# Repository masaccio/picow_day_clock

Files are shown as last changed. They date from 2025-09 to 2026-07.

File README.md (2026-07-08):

# Raspberry Pi Pico Day of Week Clock

## Current status

This project **is a work in progress**.

The clock is now feature complete from a software perspective though if this were scaled up for sale, it would need user-level configuration using a Wi-Fi connection and a web-server to provide the credentials and would also need some means of initiating a factory reset. Better still would be bluetooth discovery from a phone app to configure the clock for things like timezones, colors and fonts as well as the Wi-Fi credentials. The clock build looks like this:

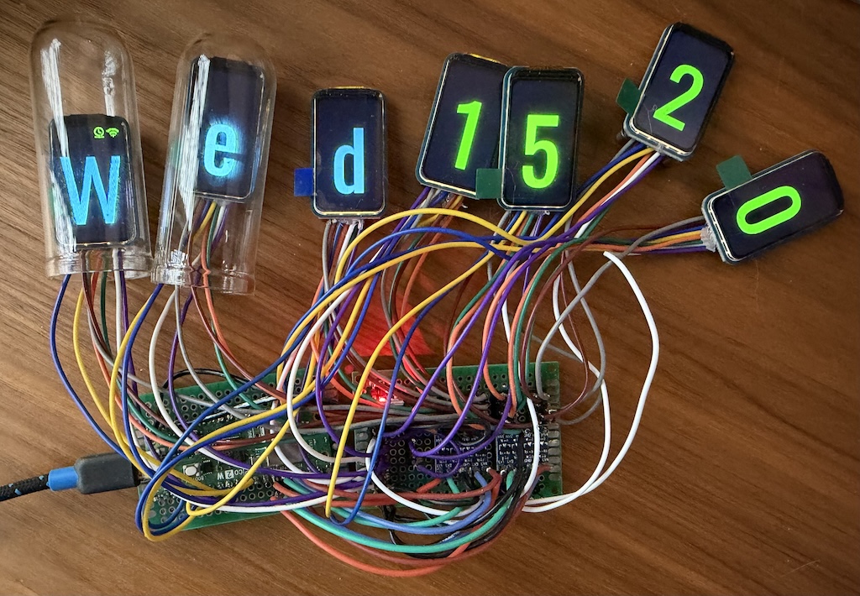
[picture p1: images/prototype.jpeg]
Current prototype


Next steps in the project are:

* Move away from the Waveshare LCD as they are quite bulky despite my surgery and I now plan to build my own backlight circuitry and drive a bare LCD
* Add a factory reset button to the design (software is complete)
* Add an alarm LED to the design for terminal failure of the LCDs or any other unrecoverable fault
* Design a 2-layer PCB to host the design as the current soldered design is too fragile
* Build a walnut enclosure

## Introduction

This project is the software, hardware design and clock enclosure design for an LCD clock driven by the Raspberry Pi Pico 2 W. The clock design is inspired by the idea of a [Nixie](https://en.wikipedia.org/wiki/Nixie_tube) clock but uses LCDs so that the display is brighter and clearly visible in daylight. The clock is intended to be wall-mounted so the read is left a little messy to simplify the electronics build.

The project is *not* compatible with earlier versions of the Pico and requires the CYW43439 Wi-Fi chip present in the Pico 2 W to function correctly.

## Software Operation

The pin-out and Wi-Fi settings are hard-coded into the project at build time. After the Pico firmware boots, the software will:

* Initialize all 7 LCD modules writing to the UART and exiting if this fails
* Create a Wi-Fi connection to the hard-coded Wi-Fi network
* Get the current time from public NTP servers
* Display the abbreviated day of week on the first three LCDs and the current time in hours in minutes on the remaining 4 displays

NTP syncs start at once per day and respect back-off requests from the server if this is too frequent. The timer itself runs once per second and any NTP drift that occurs daily is compensated for in these timer callbacks.

### Diagnostics

A watchdog timer runs on the clock and reboots the Pico if there is no activity for `WATCHDOG_TIMEOUT_MS` which is 3 seconds by default. On reboot, the clock reconnects to Wi-Fi and resyncs with NTP.

The clock displays icons along the top edge of LCD1 when errors occur. The icons indicate watchdog status, NTP status and Wi-Fi status. They are coloured red for errors and green for normal status and indicate the nature of the error that occurred such as a Wi-Fi authentication problem or network timeout.

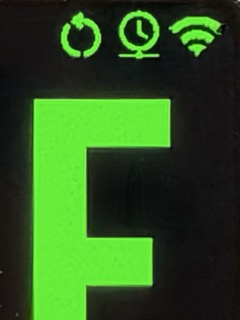
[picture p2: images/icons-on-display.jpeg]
Example display icons


If the LCD cannot be initialized, the clock prints diagnostics to `stdout` as a last resort.

### Timezones and Daylight Saving Time

The software takes into consideration daylight saving time (DST) and timezones as configured in flash. Timezones are configured as hour/half-hour offsets matching those known across the globe. The following DST rules are available which covers all regions:

| Region / Pattern | DST Start Rule (Clocks go forward) | DST End Rule (Clocks go back) | Shift |
| --- | --- | --- | --- |
| **None** (Japan, India, Arizona, Hawaii) | *Does not observe DST* | *Does not observe DST* | 0 |
| **North America** (US, Canada) | 2nd Sunday in March at 02:00 | 1st Sunday in November at 02:00 | +1 Hour |
| **Europe / UK** (EU, UK, Switzerland) | Last Sunday in March at 01:00 UTC | Last Sunday in October at 01:00 UTC | +1 Hour |
| **Australia** (Most states) | 1st Sunday in October at 02:00 | 1st Sunday in April at 03:00 | +1 Hour |
| **New Zealand** | Last Sunday in September at 02:00 | 1st Sunday in April at 03:00 | +1 Hour |
| **Chile** | 1st Saturday in September at 24:00 | 1st Saturday in April at 24:00 | +1 Hour |
| **Israel** | Friday before the last Sunday in March | Last Sunday in October at 02:00 | +1 Hour |

## Configuration

Configuration is stored in Flash and the clock will reconfigure itself when:

* an invalid configuration is detected in flash
* the factory reset button is held for 3 seconds during boot
* the factory reset button is held for 3 seconds normal operation

If factory reset is hed during boot, the clock will erase the stored flash configuration regardless of whether it is valid or not making holding the reset during normal operation harmless until the configuration is saved.

During configuration, the clock starts a Wi-Fi access point with the prefix `Pico-Day-Clock-Setup` and the last part of the Pico's MAC address. Connecting a device to this Wi-Fi network should start a captive portal, but if not, the clock's default IP address is `192.168.4.1` and you can direct your browser to `http://192.168.4.1/`. The following form configures the clock:

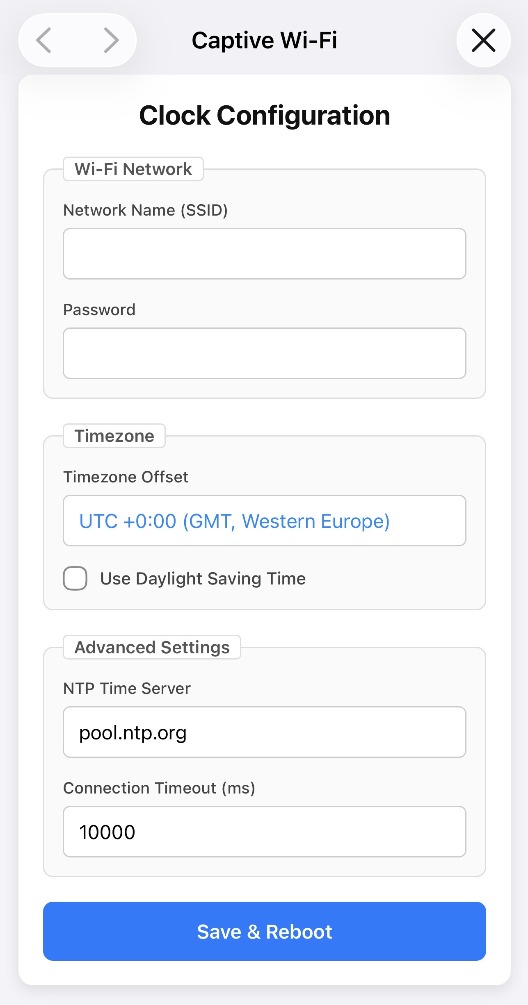
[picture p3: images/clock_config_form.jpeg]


The minimum setup is a valid Wi-Fi SSID and password. If the password is incorrect, you must force a factory reset as the clock will try indefinitely to connect to the configured Wi-Fi.

## Build and Testing

The software is expected to build on Mac, Linux and Windows hosts and should be able to be imported into the Raspberry Pi Pico extension to Visual Studio Code. The Pico target build uses the standard Pico SDK tooling, but the native tests and coverage require LLVM for Clang and the coverage tools.

Tests for the core clock functionality and error handling is largely complete through some very basic mocking of the Pico SDK. The [code](tests/mock.c) for the mocking is by no means complete and is just the very minimum required to make the clock function and generate errors that might occur such as DNS timeouts.

The tests run on the host and assume Clang is available. **Windows hosts are unsupported for testing** as the host implementation of `time_t` is incompatible with the NTP implementation which assumes uses timestamps starting in 1900 and in turn this requires 64-bit `time_t`.

Automated CI is provided by [GitHub runners](.github/workflows/build.yml).

## Debug

On boot, all LCDs are initialized first and diagnostic messages are displayed on the LCD1 as Wi-Fi and then NTP is initialized. On success, the clock starts. If any error is unrecoverable, signaled by a status message in red, the clock will not start and the diagnostics will remain. If the diagnostics do not appear at all, there is a problem with the LCD connections or the LCD driver. The following CMake configuration is available for debug to the UART:

* `CLOCK_DEBUG_ENABLED`: debug messages from the day of week clock itself
* `PICO_CYW43_ARCH_DEBUG_ENABLED`: SDK built-in debug of Wi-FI connections
* `LWIP_MALLOC_DEBUG`: SDK built-in memory allocation debug
* `LWIP_PROTOCOL_DEBUG`: SDK built-in UDP debug

## Pico pinout

The pinout for the LCD is defined in `config.h` using a series of C macros `LCD1_GPIO_xxx`. The backlight is shared across all of the LCDs as there is no need to control the dimming of the LCDs individually.

| Pin to device mapping | Name | Pin | Pico  | Pin | Name | Pin to device mapping |
|---|---|-----| ----- |-----|---|---|
| Debug Probe RX | GP0 | 1 | XXXXX | 40  | VBUS 5V | |
| Debug Probe TX | GP1 | 2 | XXXXX | 39  | VSYS 5V | DollaTek VIN |
| Debug Probe GND | GND | 3 | XXXXX | 38  | GND | LCD GND |
| LCD 1 chip select (CS) | GP2 | 4 | XXXXX | 37  | 3V3 En | |
| LCD 2 chip select (CS) | GP3 | 5 | XXXXX | 36  | 3V3 Out | |
| LCD 3 chip select (CS) | GP4 | 6 | XXXXX | 35  | ADC VRef  | |
| LCD 4 chip select (CS) | GP5 | 7 | XXXXX | 34  | GP28 A2 | |
| | GND | 8 | XXXXX | 33  | ADC Gnd | |
| LCD 5 chip select (CS) | GP6 | 9 | XXXXX | 32  | GP27 A1 | |
| LCD 6 chip select (CS) | GP7 | 10  | XXXXX | 31  | GP26 A0 | |
| LCD 7 chip select (CS) | GP8 | 11  | XXXXX | 30  | RUN | |
| Factory reset | GP9 | 12  | XXXXX | 29  | GP22 | |
| | GND | 13  | XXXXX | 28  | GND | |
| Shared clock (CLK) | GP10 | 14  | XXXXX | 27  | GP21 | |
| Shared MOSI (DIN) | GP11 | 15  | XXXXX | 26  | GP20 | |
| Shared reset (RST) | GP12 | 16  | XXXXX | 25  | GP19 | |
| Shared backlight (BL) | GP13 | 17  | XXXXX | 24  | GP18 | |
| | GND | 18  | XXXXX | 23  | GND | |
| Shared data/command (DC) | GP14 | 19  | XXXXX | 22  | GP17 | |
| Diagnostic LED | GP15 | 20  | XXXXX | 21  | GP16 | |

## Electrical Design

The LCD module expects a 3.3V supply and the [datasheet for the Waveshare 1.47inch LCD](https://files.waveshare.com/upload/9/99/1.47inch_LCD_Datasheet.pdf) indicates that the backlight draws 60-90mA. All the LCDs can therefore be driven by a single voltage regulator such as the DollaTek 1117:

* VIN: 5V VSYS from the USB power supply shared with the Pico
* VOUT: LCD VCC, shared across all LCD modules
* GND: any GND pin on the Pico

The BL backlight pin of the LCD module is not the actual  LCD backlight; it is a control pin to the LCD module's TXB0108PWR level shifter so can also be shared across all LCDs and, like the other control signals, driven directly from the Pico.

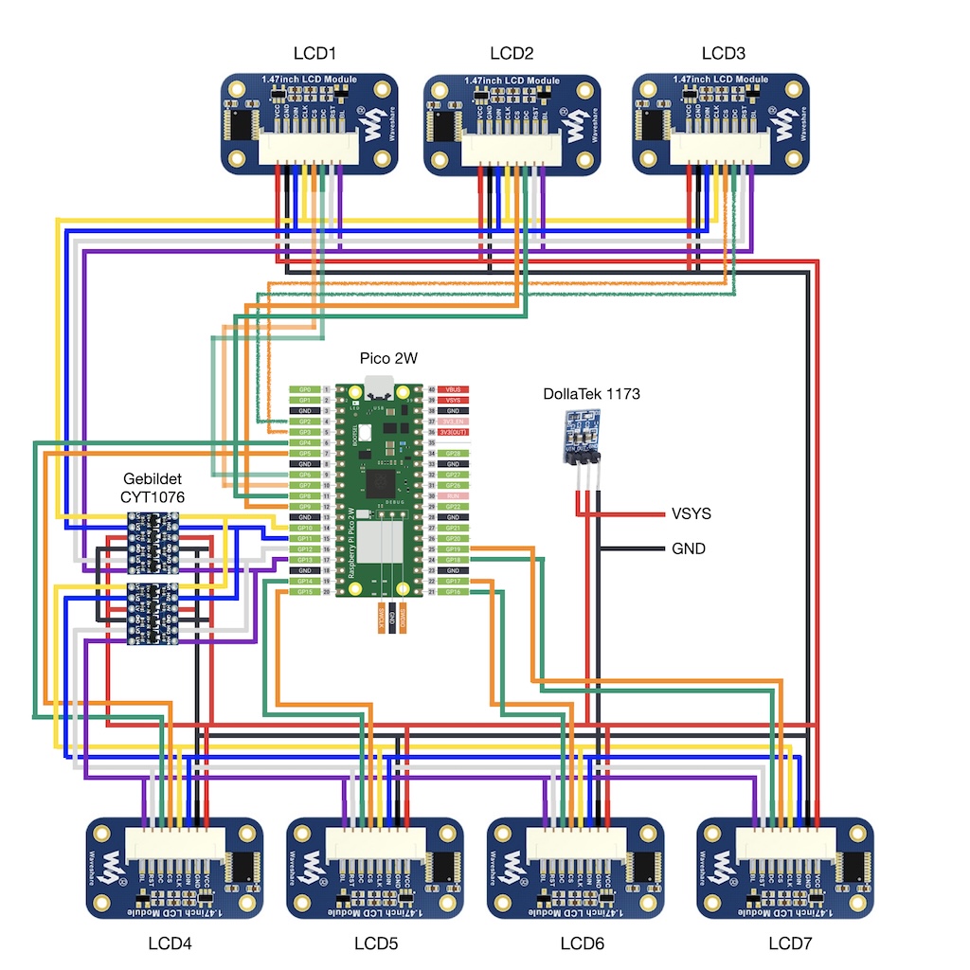
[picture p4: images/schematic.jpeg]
Clock schematic diagram


The Pico has insufficient drive strength to drive the control signals of 7 LCDs simultaneously, so a logic level converter with the VA and VB tied to 3V3 is used to increase the drive strength and buffer between the Pico and the LCDs. Care must be taken to choose a level shift with sufficient drive strength; a single TXB0108 proved insufficient and the final design uses two four-channel Gebildet CYT1076 level shifters. One CYT1076 drives the day of week LCDs (LCD1-3) and the other the time LCDs (LCD4-7).

## Mechanical design

I chose the Waveshare LCD because it comes with a socket that has a wired plug with 2.54mm pin connectors for easy prototyping. For the final clock, this connector gets in the way of the wires hiding neatly behind the LCD. There are 172x320 LCD displays that are based on the ST7789 that come with an FPC connector which is neatly connected on the narrow edge of the display. The bare LCD with the FPC connector has the disadvantage for the hobbyist that you need to add a ZIF socket and then break that out into something with a wider pitch to solder. The connector on the Waveshare board can be desoldered using solder braid and the connector carefully snipped off using flush snippers. The Waveshare module also has 2mm brass mounting holes which makes mounting the LCDs securely simpler. The main drawback of the approach is that the read of the LCD is quite messy, but the intended use is for a wall-mounted clock. The soldered connections look like this (please forgive the terrible soldering skills; I am out of practice):

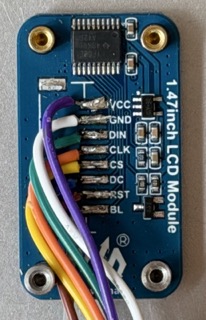
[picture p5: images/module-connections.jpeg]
Soldered connections to LCD module


The glass domes appear to be referred to as "glass dome cloche covers with cork bases" and are available from Chinese manufactures on sites like [TEMU](https://www.temu.com/). Since the class is reasonably heavy 2mm thick glass, the 25mm domes are too narrow in the internal diameter for the LCD so 28mm domes are required. Unfortunately 71mm long so they need to sit about 25mm below the top of the clock so that the LCDs are comfortable in the upper section of the dome. The domes sit inside a 4mm brass frame to which the LCDs can be held using M2 machine screws:

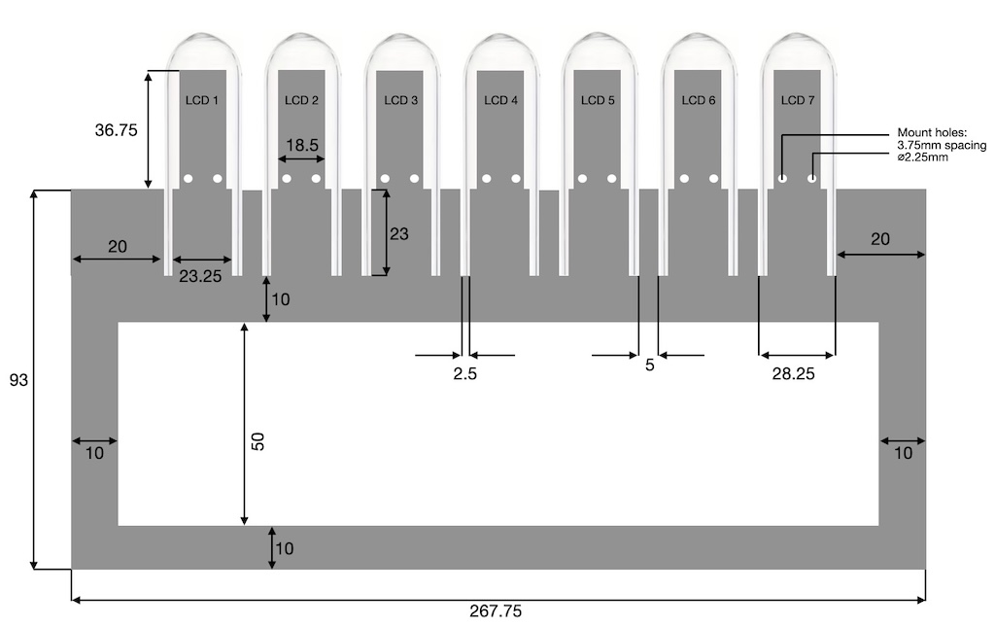
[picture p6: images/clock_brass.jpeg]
Brass plate design


The brass frame is laser cut from 4mm brass using a CAD file that is generated using `scripts/generate-dxf.py`. Assuming CMake has generated the Python virtual environment in the `build` folder, you can build the DXF file (`generated/clock_brass.dxf`) using:

``` bash
source build/scripts_venv/bin/activate
pip install ezdxf
python3 scripts/create-cad-drawing.py
```

It's also possible to generate a 3D model using Python for use as a 3D printing prototype to check that that everything aligns correctly:

``` bash
source build/scripts_venv/bin/activate
pip install cadquery cadquery-ocp
python3 scripts/create-3d-model.py
```

The brass frame is then sandwiched between two rectangular woden boxes with no lids. The USB power cable is fed through one box and plugs into the Pico's USB port which simplifies the electrical design.

## Credits

ST7789 init and driver code is derived from the [Waveshare Sample Demo](https://www.waveshare.com/wiki/1.47inch_LCD_Module) for the Waveshare 1.47inch LCD. The driver is [licensed](licenses/waveshare.txt) by the Waveshare team under an MIT license.

NTP driver code is derived from [pico_ntp_client](https://github.com/raspberrypi/pico-examples/tree/master/pico_w/wifi/ntp_client) in the [Raspberry Pi Pico SDK Examples](https://github.com/raspberrypi/pico-examples) which is [licensed](raspberry-pi.txt) under a BSD license.

The access point and associated DHCP/DNS server are derived from [pico_access_point](https://github.com/raspberrypi/pico-examples/tree/master/pico_w/wifi/access_point) in the [Raspberry Pi Pico SDK Examples](https://github.com/raspberrypi/pico-examples) which is [licensed](raspberry-pi.txt) under a BSD license.

Variable width fonts replace the fixed-width fonts in the Waveshare examples, but the C data structures are ultimately derived from work by STMicroelectronics [licensed](licenses/stm.txt) under the 3-clause BSD license.

The digit fonts included in the repository are [Bebas Neue Regular](https://fonts.google.com/specimen/Bebas+Neue) which is [licensed](licenses/BebasNeue-OFL.txt) under the Open Font License, and [Oswald](https://fonts.google.com/specimen/Oswald) which is also [licensed](licenses/Oswald-OFL.txt) under the Open Font License.

The text font used in display diagnostics during boot is [Roboto Medium](https://fonts.google.com/specimen/Roboto) which is [licensed](licenses/Roboto-OFL.txt) under the Open Font License.

Icons in this project are derived from [Google Material Design Icons](https://github.com/google/material-design-icons), which are licensed under the [Apache License 2.0](https://github.com/google/material-design-icons/blob/master/LICENSE). The icons have been resized and converted to C bitmaps for use in this project, and new icons have been derived to addition status badges.

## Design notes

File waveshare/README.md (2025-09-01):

# Waveshare 1.47inch LCD Module

The files here are copied from the [Waveshare Wiki](https://www.waveshare.com/wiki/1.47inch_LCD_Module) for the 1.47 inch LCD Module which is based off the ST7789V3 chipset.

The driver has been modified as follows:

* I2C and Infrared has been removed since the LCD used in this project only uses SPI.
* The pin configuration in `Dev_Config.h` has been replaced by config passed to `DEV_Module_Init()` to enable multiple displays from the single driver.

## Pico pinout

| Pin to device mapping | Name | Pin | Pico  | Pin | Name | Pin to device mapping  |
|---|---|-----| ----- |-----|---|---|
| Debug Probe RX | GP0 | 1 | XXXXX | 40  | VBUS 5V | |
| Debug Probe TX | GP1 | 2 | XXXXX | 39  | VSYS 5V | |
| Debug Probe GND | GND | 3 | XXXXX | 38  | GND | LCD GND |
| | GP2 | 4 | XXXXX | 37  | 3V3 En | |
| | GP3 | 5 | XXXXX | 36  | 3V3 Out | LCD VCC |
| | GP4 | 6 | XXXXX | 35  | ADC VRef  | |
| | GP5 | 7 | XXXXX | 34  | GP28 A2 | |
| | GND | 8 | XXXXX | 33  | ADC Gnd | |
| LCD 1 data/command (DC) | GP6 | 9 | XXXXX | 32  | GP27 A1 | |
| LCD 1 chip select (CS)  | GP7 | 10  | XXXXX | 31  | GP26 A0 | |
| LCD 2 data/command (DC) | GP8 | 11  | XXXXX | 30  | RUN | |
| LCD 2 chip select (CS)  | GP9 | 12  | XXXXX | 29  | GP22 | |
| | GND | 13  | XXXXX | 28  | GND | |
| Shared clock (CLK) | GP10 | 14  | XXXXX | 27  | GP21 | |
| Shared MOSI (DIN) | GP11 | 15  | XXXXX | 26  | GP20 | |
| Shared reset (RST) | GP12 | 16  | XXXXX | 25  | GP19 | |
| Shared backlight (BL) | GP13 | 17  | XXXXX | 24  | GP18 | |
| | GND | 18  | XXXXX | 23  | GND | |
| | GP14 | 19  | XXXXX | 22  | GP17 | |
| | GP15 | 20  | XXXXX | 21  | GP16 | |

## LCD connections

The default GPIO configuration is assumed, as defined in `lib/Config/DEV_Config.h`:

| Pico | LCD 1 | LCD 2 |
|---|---|---|
| 3V3 Out | VCC | VCC |
| GND | GND | GND |
| GP11 | DIN | DIN |
| GP10 | CLK | CLK |
| GP7 | CS | |
| GP6 | DC | |
| GP9 | | CS |
| GP8 | | DC |
| GP12 | RST | RST |
| GP13 | BL | BL |

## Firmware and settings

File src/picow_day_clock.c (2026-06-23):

#ifndef WIFI_SSID
#error "WIFI_SSID is not defined. Please define it in config.cmake or via a compile flag."
#endif

#ifndef WIFI_PASSWORD
#error "WIFI_PASSWORD is not defined. Please define it in config.cmake or via a compile flag."
#endif

#include <stdio.h>
#include <string.h>
#include <sys/time.h>
#include <time.h>

// Pico SDK
#ifndef TEST_MODE
#include "hardware/flash.h"
#include "hardware/gpio.h"
#include "hardware/sync.h"
#include "hardware/watchdog.h"
#include "pico/stdlib.h"
#include "pico/time.h"
#include "pico/util/datetime.h"
#else
#include "mock.h"
#include "test.h"

extern int test_main(void);
#endif

// Local includes
#include "bitmap.h"
#include "clock.h"
#include "config.h"

typedef struct
{
    uint16_t DC;
    uint16_t CS;
} lcd_pin_config_t;

static lcd_pin_config_t lcd_pin_config[NUM_LCDS] = {
    /* LCD 1 */ {.DC = LCD1_GPIO_DC, .CS = LCD1_GPIO_CS},
    /* LCD 2 */ {.DC = LCD2_GPIO_DC, .CS = LCD2_GPIO_CS},
    /* LCD 3 */ {.DC = LCD3_GPIO_DC, .CS = LCD3_GPIO_CS},
    /* LCD 4 */ {.DC = LCD4_GPIO_DC, .CS = LCD4_GPIO_CS},
    /* LCD 5 */ {.DC = LCD5_GPIO_DC, .CS = LCD5_GPIO_CS},
    /* LCD 6 */ {.DC = LCD6_GPIO_DC, .CS = LCD6_GPIO_CS},
    /* LCD 7 */ {.DC = LCD7_GPIO_DC, .CS = LCD7_GPIO_CS},
};

#define STATUS_CASE(STATUS)                                                                                            \
    case STATUS:                                                                                                       \
        return #STATUS;

const char *watchdog_error_to_string(watchdog_error_t status)
{
    switch (status) {
        STATUS_CASE(WATCHDOG_OK)
        STATUS_CASE(WATCHDOG_RESET)
        STATUS_CASE(WATCHDOG_NTP)
        STATUS_CASE(WATCHDOG_WIFI)
    }
    return "UNKNOWN_STATUS";
}

const char *ntp_error_to_string(ntp_error_t status)
{
    switch (status) {
        STATUS_CASE(NTP_OK)
        STATUS_CASE(NTP_INIT_ERROR)
        STATUS_CASE(NTP_DNS_ERROR)
        STATUS_CASE(NTP_TIMEOUT_ERROR)
        STATUS_CASE(NTP_PROTOCOL_ERROR)
        STATUS_CASE(NTP_MEMORY_ERROR)
    }
    return "UNKNOWN_STATUS";
}

const char *wifi_error_to_string(wifi_error_t status)
{
    switch (status) {
        STATUS_CASE(WIFI_OK)
        STATUS_CASE(WIFI_INIT_ERROR)
        STATUS_CASE(WIFI_TIMEOUT_ERROR)
        STATUS_CASE(WIFI_AUTH_ERROR)
        STATUS_CASE(WIFI_CONNECT_ERROR)
        STATUS_CASE(WIFI_UNKNOWN_ERROR)
    }
    return "UNKNOWN_STATUS";
}

volatile uint trigger_ap_mode = 0;

#ifdef TEST_MODE
// In test mode, we want to return from main() but fatal_error() cannot return
// so we use setjmp/longjmp to break out
#include <setjmp.h>

static jmp_buf fatal_jmp_buf;
persistent_state_t persistent_state;

extern void mock_update_icons(watchdog_error_t watchdog_error, ntp_error_t ntp_error, wifi_error_t wifi_error);
extern lcd_state_t *mock_lcd_init(uint16_t RST_gpio, uint16_t DC_gpio, uint16_t BL_gpio, uint16_t CS_gpio,
                                  uint16_t CLK_gpio, uint16_t MOSI_gpio, int reset);
extern void mock_reset_icons(void);

// In test mode, key status updates to the LCD are treated like a printf()
// so that the test harness can check the sequence of events.
#define lcd_print_line(state, line_num, color, msg)                                                                    \
    (void)line_num;                                                                                                    \
    (void)color;                                                                                                       \
    mock_printf(msg)
#define lcd_clear_screen(...) (void)0
#define lcd_print_clock_digit(...) (void)0

static void __attribute__((noreturn)) fatal_reset(clock_state_t *state, ntp_error_t ntp_error, wifi_error_t wifi_error)
{
    (void)state;
    mock_printf("Watchdog: %s/%s", ntp_error_to_string(ntp_error), wifi_error_to_string(wifi_error));
    persistent_state.ntp_error = ntp_error;
    persistent_state.wifi_error = wifi_error;
    mock_ctx.spy.fatal_ntp_error = ntp_error;
    mock_ctx.spy.fatal_wifi_error = wifi_error;
    watchdog_reboot((uint32_t)0, SRAM_END, (uint32_t)0 /* delay_ms */);
    // Returns into main() which will then exit with status=1
    longjmp(fatal_jmp_buf, 1);
}
#else // Pico target
persistent_state_t persistent_state __attribute__((section(".uninitialized_data")));

static void __attribute__((noreturn)) fatal_reset(clock_state_t *state, ntp_error_t ntp_error, wifi_error_t wifi_error)
{
    lcd_update_icons(state->lcd_states[0], WATCHDOG_RESET, ntp_error, wifi_error);
    persistent_state.ntp_error = ntp_error;
    persistent_state.wifi_error = wifi_error;
    watchdog_reboot((uint32_t)0, SRAM_END, (uint32_t)0 /* delay_ms */);
    while (1)
        __wfi(); // hang until reset
}
#endif

static char day_of_week_str[][4] = {"Sun", "Mon", "Tue", "Wed", "Thu", "Fri", "Sat"};

// Callback from NTP called when an NTP request is successful
void ntp_timer_callback(void *state, time_t *ntp_time)
{
    clock_state_t *clock_state = (clock_state_t *)state;
    clock_state->ntp_time = *ntp_time;
}

int last_weekday_of_month(int day, int month, int year)
{
    // Compute the last day of the month using Zeller's congruence
    // See https://en.wikipedia.org/wiki/Zeller%27s_congruence
    if (month < 3) {
        month += 12;
        year -= 1;
    }
    int K = year % 100;
    int J = year / 100;
    int h = (day + (13 * (month + 1)) / 5 + K + K / 4 + J / 4 + 5 * J) % 7;

    // Zeller: 0=Saturday so convert to Unix-offset where 0=Sunday
    return (h + 6) % 7;
}

// target_wday: 0=Sunday, 1=Monday, ..., 6=Saturday
// n: 1 for 1st, 2 for 2nd... -1 for LAST
static int nth_weekday(int n, int target_wday, int month, int year)
{
    int dow_first = last_weekday_of_month(1, month, year);
    int first_occurrence = 1 + (target_wday - dow_first + 7) % 7;

    if (n > 0) {
        return first_occurrence + (n - 1) * 7;
    } else {
        int last = first_occurrence + 28;
        int days_in_month[] = {0, 31, 28, 31, 30, 31, 30, 31, 31, 30, 31, 30, 31};

        if (year % 4 == 0 && (year % 100 != 0 || year % 400 == 0)) {
            days_in_month[2] = 29;
        }
        if (last > days_in_month[month]) {
            last -= 7;
        }
        return last;
    }
}

// The Pico SDK doesn't have timegm() for UTC calculations since it doesn't
// manage timezones, but for testing we need to ensure we stick to UTC
time_t tm_to_epoch(struct tm *tm)
{
#if defined(__APPLE__) || defined(__linux__)
    return timegm(tm); // UTC on host
#else
    return mktime(tm); // Pico: local = UTC
#endif
}

// Generates the Unix Epoch bounds for DST based on the current year
static void get_dst_bounds(dst_rule_t rule, int year, time_t *start, time_t *end)
{
    struct tm ts = {0}, te = {0};
    ts.tm_year = year - 1900;
    te.tm_year = year - 1900;

    switch (rule) {
        case DST_RULE_NA: // 2nd Sun Mar (02:00) to 1st Sun Nov (02:00)
            ts.tm_mon = 2;
            ts.tm_mday = nth_weekday(2, 0, 3, year);
            ts.tm_hour = 2;
            te.tm_mon = 10;
            te.tm_mday = nth_weekday(1, 0, 11, year);
            te.tm_hour = 2;
            break;

        case DST_RULE_EU: // Last Sun Mar (01:00) to Last Sun Oct (01:00)
            ts.tm_mon = 2;
            ts.tm_mday = nth_weekday(-1, 0, 3, year);
            ts.tm_hour = 1;
            te.tm_mon = 9;
            te.tm_mday = nth_weekday(-1, 0, 10, year);
            te.tm_hour = 1;
            break;

        case DST_RULE_AU: // 1st Sun Oct (02:00) to 1st Sun Apr (03:00)
            ts.tm_mon = 9;
            ts.tm_mday = nth_weekday(1, 0, 10, year);
            ts.tm_hour = 2;
            te.tm_mon = 3;
            te.tm_mday = nth_weekday(1, 0, 4, year);
            te.tm_hour = 3;
            break;

        case DST_RULE_NZ: // Last Sun Sep (02:00) to 1st Sun Apr (03:00)
            ts.tm_mon = 8;
            ts.tm_mday = nth_weekday(-1, 0, 9, year);
            ts.tm_hour = 2;
            te.tm_mon = 3;
            te.tm_mday = nth_weekday(1, 0, 4, year);
            te.tm_hour = 3;
            break;

        case DST_RULE_CL: // 1st Sat Sep (24:00) to 1st Sat Apr (24:00)
            ts.tm_mon = 8;
            ts.tm_mday = nth_weekday(1, 6, 9, year);
            ts.tm_hour = 23;
            ts.tm_min = 59;
            te.tm_mon = 3;
            te.tm_mday = nth_weekday(1, 6, 4, year);
            te.tm_hour = 23;
            te.tm_min = 59;
            break;

        case DST_RULE_IL: // Fri before last Sun Mar to Last Sun Oct (02:00)
            ts.tm_mon = 2;
            ts.tm_mday = nth_weekday(-1, 0, 3, year) - 2;
            ts.tm_hour = 2;
            te.tm_mon = 9;
            te.tm_mday = nth_weekday(-1, 0, 10, year);
            te.tm_hour = 2;
            break;

        case DST_RULE_NONE:
            *start = 0;
            *end = 0;
            return;
    }

    *start = tm_to_epoch(&ts);
    *end = tm_to_epoch(&te);
}

// Determines if a given UTC time requires a 1-hour shift
int time_is_dst(time_t utc_now, clock_state_t *state)
{
    dst_rule_t dst_rule = state->clock_config.dst_rule;
    if (dst_rule == DST_RULE_NONE)
        return 0;

    struct tm *utc_tm = gmtime(&utc_now);
    int year = utc_tm->tm_year + 1900;

    time_t start_time, end_time;
    get_dst_bounds(dst_rule, year, &start_time, &end_time);

    if (start_time < end_time) {
        return (utc_now >= start_time && utc_now < end_time); // Northern
    } else {
        return (utc_now >= start_time || utc_now < end_time); // Southern Wrap
    }
}

static time_t calculate_local_time(time_t utc_now, clock_state_t *state)
{
    time_t local_time = utc_now + (state->clock_config.tz_offset_mins * 60);

    if (time_is_dst(utc_now, state)) {
        local_time += 3600;
    }

    return local_time;
}

const char *time_as_string(time_t t, clock_state_t *state)
{
    static char buffer[32];
    struct tm tm_local;

    time_t local_epoch = calculate_local_time(t, state);
    gmtime_r(&local_epoch, &tm_local);

    const char *suffix = "";
    if (time_is_dst(t, state)) {
        suffix = " (DST)";
    }
    snprintf(buffer, sizeof(buffer), "%02d:%02d:%02d%s", tm_local.tm_hour, tm_local.tm_min, tm_local.tm_sec, suffix);

    return buffer;
}

static void set_time_of_day(clock_state_t *state)
{
    struct timeval tv;
    tv.tv_sec = state->ntp_time;
    tv.tv_usec = 0;
    settimeofday(&tv, NULL);
}

bool clock_timer_callback(repeating_timer_t *t)
{
    clock_state_t *state = (clock_state_t *)t->user_data;

    watchdog_update();

    // Adjust the NTP drift a second at a time
    if (state->ntp_drift > 0) {
        state->ntp_drift--;
    } else if (state->ntp_drift < 0) {
        state->ntp_drift++;
    }
    time_t local_epoch = calculate_local_time(time(NULL), state) + state->ntp_drift;
    struct tm local_time;
    gmtime_r(&local_epoch, &local_time);

    // Clear any watchdog error icon after it's been displayed a while
    if (local_epoch > (state->last_watchdog_error + WATCHDOG_ICON_INTERVAL)) {
        state->watchdog_reset_error = WATCHDOG_OK;
    }

    static uint8_t button_hold_seconds = 0;
    // Check the physical state of the button (0 means pressed due to pull-up)
    if (gpio_get(CONFIG_BUTTON_GPIO) == 0) {
        button_hold_seconds++;
        CLOCK_DEBUG("Configuration mode selected %d second(s)\n", button_hold_seconds);

        if (button_hold_seconds >= CONFIG_BUTTON_HOLD_SECONDS) {
            button_hold_seconds = 0;
            CLOCK_DEBUG("Configuration mode triggered!\n");
            trigger_ap_mode = 1;
        }
    } else {
        button_hold_seconds = 0;
    }

    if (state->first_clock_tick == 0 || local_time.tm_sec == 0) {
        CLOCK_DEBUG("%s, timestamp=%llu, boot_count=%lu, ntp_reset_error=%d, wifi_reset_error=%d, NTP=%s\r\n",
                    time_as_string(local_epoch, state), local_epoch, persistent_state.boot_count,
                    state->ntp_reset_error, state->wifi_reset_error, ntp_error_to_string(state->ntp_state->error));

        static char lcd_digits[NUM_LCDS + 1];
        strncpy(lcd_digits, day_of_week_str[local_time.tm_wday], 3);

        lcd_digits[3] = '0' + (char)(local_time.tm_hour / 10);
        lcd_digits[4] = '0' + (char)(local_time.tm_hour % 10);
        lcd_digits[5] = '0' + (char)(local_time.tm_min / 10);
        lcd_digits[6] = '0' + (char)(local_time.tm_min % 10);
        lcd_digits[7] = '\0';

        for (unsigned int ii = 0; ii < NUM_LCDS; ii++) {
            if (state->current_lcd_digits[ii] != lcd_digits[ii]) {
                lcd_clear_screen(state->lcd_states[ii], BLACK);
                lcd_print_clock_digit(state->lcd_states[ii], (ii < 3) ? CYAN : GREEN, lcd_digits[ii]);
            }
            if (ii == 0) {
                lcd_update_icons(state->lcd_states[0], state->watchdog_reset_error, state->ntp_state->error, WIFI_OK);
            }
            state->current_lcd_digits[ii] = lcd_digits[ii];
        }

        if ((local_epoch - state->ntp_last_sync) >= state->ntp_interval) {
            ntp_error_t ntp_error_status = ntp_get_time(state->ntp_state);
            if (state->ntp_state->status == NTP_KOD) {
                state->ntp_interval *= 2;
                CLOCK_DEBUG("NTP: backing off: new delay is %d minutes\r\n", state->ntp_interval);
            } else if (ntp_error_status != NTP_OK) {
                state->ntp_last_sync = local_epoch;
                CLOCK_DEBUG("NTP: get time failed with error %d\r\n", ntp_error_status);
                lcd_update_icons(state->lcd_states[0], state->watchdog_reset_error, state->ntp_state->error, WIFI_OK);
            } else {
                int drift = (int)state->ntp_time - (int)local_epoch;
                CLOCK_DEBUG("NTP sync at %s; drift = %ds\r\n", time_as_string(state->ntp_time, state), drift);
                state->ntp_last_sync = state->ntp_time;
                state->ntp_drift = drift;
                set_time_of_day(state);
            }
        }
        state->first_clock_tick = 1;
    }

    return 1; // Keep repeating
}

int config_store_handler(clock_config_t *config)
{
    config->magic_marker = CONFIG_MAGIC;
    uint32_t interrupts = save_and_disable_interrupts();
    flash_range_erase(FLASH_TARGET_OFFSET, FLASH_SECTOR_SIZE);
    flash_range_program(FLASH_TARGET_OFFSET, (uint8_t *)config, sizeof(clock_config_t));
    restore_interrupts(interrupts);

    CLOCK_DEBUG("Stored new config in flash\r\n");
    return 0;
}

#ifdef TEST_MODE
// In test mode, main() always returns, even in the case of a fatal error
// as we need to that fatal errors happened for the correct reasons.
int test_main(void)
{
    static int test_main_watchdog_reentry;
    mock_reset_icons();
    mock_printf("Test init\n");
    test_main_watchdog_reentry = 0;
    mock_ctx.spy.watchdog_reboot_called = 0;
    if (setjmp(fatal_jmp_buf)) {
        test_main_watchdog_reentry = 1;
        mock_ctx.spy.fatal_reset_caught = 1;
    }
#else
int main(void)
{
#endif

    stdio_init_all();

    gpio_init(CONFIG_BUTTON_GPIO);
    gpio_set_dir(CONFIG_BUTTON_GPIO, GPIO_IN);
    gpio_pull_up(CONFIG_BUTTON_GPIO);

    clock_state_t *state = (clock_state_t *)calloc(1, sizeof(clock_state_t));
    if (state == NULL) {
        // Unrecoverable state and no chance to display status on the LCD
#ifdef TEST_MODE
        mock_ctx.spy.clock_state_alloc_failed = 1;
#endif
        printf("Failed to allocate clock state\r\n");
        return 1;
    }
    for (unsigned int ii = 0; ii < NUM_LCDS; ii++) {
        // Reset is shared so only need to do this once
        int reset = (ii == 0);
        state->lcd_states[ii] = lcd_init(/* RST  */ LCD_GPIO_RST,
                                         /* DC   */ lcd_pin_config[ii].DC,
                                         /* BL   */ LCD_GPIO_BL,
                                         /* CS   */ lcd_pin_config[ii].CS,
                                         /* CLK  */ LCD_GPIO_CLK,
                                         /* MOSI */ LCD_GPIO_MOSI, reset);
        if (state->lcd_states[ii] == NULL) {
            // Unrecoverable state and no chance to display status on the LCD
#ifdef TEST_MODE
            mock_ctx.spy.lcd_init_failed = ii;
#endif
            return 1;
        }
        lcd_clear_screen(state->lcd_states[ii], BLACK);
    }

    int cold_boot = (watchdog_caused_reboot() == 0);
    if (cold_boot) {
        memset(&persistent_state, 0, sizeof(persistent_state_t));
        persistent_state.magic_marker = CONFIG_MAGIC;
        lcd_print_line(state->lcd_states[0], 2, GREEN, "LCD init successful");
        CLOCK_DEBUG("Cold boot\r\n");
    } else {
        persistent_state.boot_count++;
        CLOCK_DEBUG("Reboot: count=%lu, ntp_error=%d, wifi_error=%d\r\n", persistent_state.boot_count,
                    persistent_state.ntp_error, persistent_state.wifi_error);
        watchdog_error_t watchdog_error;
        if (persistent_state.ntp_error != NTP_OK) {
            watchdog_error = WATCHDOG_NTP;
        } else if (persistent_state.wifi_error != WIFI_OK) {
            watchdog_error = WATCHDOG_WIFI;
        } else {
            watchdog_error = WATCHDOG_RESET;
        }
        lcd_update_icons(state->lcd_states[0], watchdog_error, persistent_state.ntp_error, persistent_state.wifi_error);
        state->watchdog_reset_error = watchdog_error;
        state->ntp_reset_error = persistent_state.ntp_error;
        state->wifi_reset_error = persistent_state.wifi_error;
        persistent_state.ntp_error = NTP_OK;
        persistent_state.wifi_error = WIFI_OK;
    }

    CLOCK_DEBUG("Checking flash\r\n");
    clock_config_t *flash_config = (clock_config_t *)FLASH_CONFIG_ADDR;
    if (flash_config->magic_marker == CONFIG_MAGIC) {
        CLOCK_DEBUG("Valid config loaded from Flash\r\n");
        memcpy(&state->clock_config, flash_config, sizeof(clock_config_t));
    } else {
        CLOCK_DEBUG("Can't find valid config in Flash. Starting access point.\r\n");
        lcd_print_line(state->lcd_states[0], 3, RED, "Flash config corrupt");
        lcd_print_line(state->lcd_states[0], 4, RED, "Connect to Clock Wi-Fi");
        start_wifi_access_point(config_store_handler);
    }
    CLOCK_DEBUG("Checking flash done\r\n");

#ifdef TEST_MODE
    // Test has generated a watchdog reset and logged its outcome so we can return to the test harness now
    if (test_main_watchdog_reentry) {
        return 1;
    }
#endif
    watchdog_update();

    wifi_is_initialized = 0;
    wifi_error_t wifi_status = connect_to_wifi(WIFI_SSID, WIFI_PASSWORD);
    if (wifi_status == WIFI_OK) {
        if (cold_boot) {
            lcd_print_line(state->lcd_states[0], 3, GREEN, "Connected to WiFi");
        }
        lcd_update_icons(state->lcd_states[0], WATCHDOG_OK, NTP_OK, WIFI_OK);
    } else {
        fatal_reset(state, NTP_OK, wifi_status);
        // Never reached: reset happens
    }

    state->ntp_state = ntp_init((void *)state, ntp_timer_callback);
    if (state->ntp_state == NULL) {
        fatal_reset(state, NTP_INIT_ERROR, WIFI_OK);
        // Never reached: reset happens
    }
    ntp_error_t ntp_status = ntp_get_time(state->ntp_state);
    if (ntp_status == NTP_OK) {
        if (cold_boot) {
            lcd_print_line(state->lcd_states[0], 4, GREEN, "NTP time sync OK");
        }
        lcd_update_icons(state->lcd_states[0], WATCHDOG_OK, NTP_OK, WIFI_OK);
    } else {
        fatal_reset(state, ntp_status, WIFI_OK);
        // Never reached: reset happens
    }

    state->ntp_drift = 0;
    state->ntp_last_sync = state->ntp_time;
    state->ntp_interval = NTP_SYNC_INTERVAL_SEC;
    if (!cold_boot) {
        state->last_watchdog_error = state->ntp_time;
    }

    // Set the system clock to the NTP time
    set_time_of_day(state);

    // Call the timer every second to enable us to slowly change the clock if
    // the system clock drifts from NTP time. Let the watchdog reset the clock
    // if the timer callback has not happened in a few ticks.
    watchdog_enable(WATCHDOG_TIMEOUT_MS, /* pause_on_debug */ 1);
    sleep_ms(500);
    add_repeating_timer_ms(1 * 1000, clock_timer_callback, state, &state->timer);

#ifndef TEST_MODE
    while (1) {
        if (trigger_ap_mode) {
            trigger_ap_mode = 0;
            printf("Starting access point...\n");
            start_wifi_access_point(config_store_handler);
        }
        sleep_ms(1000);
    }
#endif

    return 0;
}

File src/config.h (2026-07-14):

#pragma once

#define FACTORY_RESET_GPIO (uint16_t)9        // Factory reset enable (Wi-Fi AP)
#define DIAG_GREEN_LED_GPIO (uint16_t)15      // LED driver for normal operation
#define DIAG_RED_LED_GPIO (uint16_t)16        // LED driver for fatal errors
#define AMBIENT_LIGHT_GPIO (uint16_t)26       // ADC pin for photo-resistor light sensor
#define AMBIENT_LIGHT_ADC_CH (uint16_t)0      // ADC pin 26 is ADC channel 0
#define AMBIENT_LIGHT_DARK (uint16_t)0x40     // ADC raw value considered low light
#define AMBIENT_LIGHT_BRIGHT (uint16_t)0x180  // ADC raw value considered bright lighting
#define BACKLIGHT_CALLBACK_TIME_MS 200        // How often to adjust the backlight
#define FACTORY_RESET_HOLD_TIME_MS 3000       // How long the factory reset button must be held for
#define HTTP_POLL_TIME_SEC 5                  // How long to allow a connection to idle
#define HTTP_TCP_PORT 80                      // Found in the SDK, but define here for portability to the host tests
#define NTP_DELTA 2208988800                  // Seconds between 1 Jan 1900 and 1 Jan 1970
#define NTP_MSG_LEN 48                        // NTP message size (fixed by lwIP)
#define NTP_DEFAULT_TIMEOUT_MS (10 * 1000)    // Time to allow for an NTP response in milliseconds
#define NTP_SYNC_INTERVAL_SEC (60 * 60 * 24)  // Sync to NTP once per day
#define NTP_DEFAULT_PORT 123                  // Default NTP port
#define NTP_DEFAULT_SERVER "pool.ntp.org"     // Default NPT server
#define NUM_LCDS 7                            // Number of LCDs (3 for day of week, 4 for time)
#define TCP_IP_BUFFER_SIZE 8192               // Needs to be large enough for the most bloated of POST responses
#define TCP_IP_MAX_CONNECTIONS 4              // Keep low to avoid RAM exhaustion from browsers making many requests
#define WATCHDOG_ICON_INTERVAL (60 * 60 * 24) // How long to hold a watchdog error icon
#define WATCHDOG_TIMEOUT_MS (5 * 1000)        // Watchdog timeout in milliseconds (HW max is ~8s)
#define WIFI_ABANDON_TIMEOUT_MS (30 * 1000)   // How long to keep retrying connection in milliseconds
#define WIFI_BAD_AUTH_RETRY_COUNT 3           // How many bad auth errors to tolerate
#define WIFI_BAD_AUTH_RETRY_DELAY_MS 500      // Time to wait before retrying after auth error in milliseconds
#define WIFI_CONNECT_TIMEOUT_MS (10 * 1000)   // Time to allow Wi-Fi driver to connect in milliseconds

#define HTTP_RESPONSE_REDIRECT_HEADER                                                                                  \
    "HTTP/1.1 302 Found\r\n"                                                                                           \
    "Location: http://%s" HTTP_CONFIG_URL "\r\n"                                                                       \
    "Connection: close\r\n"                                                                                            \
    "\r\n"
#define HTTP_RESPONSE_OK_HEADER                                                                                        \
    "HTTP/1.1 200 OK\r\n"                                                                                              \
    "Content-Type: text/html; charset=utf-8\r\n"                                                                       \
    "Connection: close\r\n"                                                                                            \
    "\r\n"
#define HTTP_CONFIG_URL "/clock-config"

#define WIFI_AP_SSID_PREFIX "Pico-Day-Clock-Setup" // Prefix will have a partial MAC address appended
#define WIFI_SSID_MAX_LEN 32                       // IEEE 802.11 standard limits
#define WIFI_PASSWORD_MAX_LEN 63                   // IEEE 802.11 standard limits
#define HOSTNAME_MAX_LEN 64                        // Maximum length for Linux FQDN

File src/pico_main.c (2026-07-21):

#include "hardware/sync.h"
#include "hardware/watchdog.h"

#include "clock.h"

persistent_state_t persistent_state __attribute__((section(".uninitialized_data")));

void __attribute__((noreturn)) fatal_reset(clock_state_t *state, ntp_error_t ntp_error, wifi_error_t wifi_error)
{
    lcd_update_icons(&state->lcd_states[0], WATCHDOG_RESET, ntp_error, wifi_error);
    persistent_state.ntp_error = ntp_error;
    persistent_state.wifi_error = wifi_error;
    watchdog_reboot((uint32_t)0, SRAM_END, (uint32_t)0 /* delay_ms */);
    while (1)
        __wfi(); // hang until reset
}

bool startup_led_callback(struct repeating_timer *t)
{
    (void)t;
    gpio_xor_mask(1 << DIAG_GREEN_LED_GPIO);
    return true;
}

static bool init_diagnostic_led(struct repeating_timer *t)
{
    gpio_init(DIAG_GREEN_LED_GPIO);
    gpio_set_dir(DIAG_GREEN_LED_GPIO, GPIO_OUT);
    gpio_put(DIAG_GREEN_LED_GPIO, 0);
    gpio_init(DIAG_RED_LED_GPIO);
    gpio_set_dir(DIAG_RED_LED_GPIO, GPIO_OUT);
    gpio_put(DIAG_RED_LED_GPIO, 0);

    return add_repeating_timer_ms(-500 /* 1Hz pulse */, startup_led_callback, NULL, t);
}

int main(void)
{
    clock_state_t state;
    clock_init(&state);

    struct repeating_timer startup_led_timer;
    bool startup_led_active = init_diagnostic_led(&startup_led_timer);

    clock_start(&state);

    while (1) {
        clock_task(&state);

        if (state.ap_mode_triggered) {
            state.ap_mode_triggered = 0;
            start_wifi_access_point(&state.flash_config, config_store_handler, &state.wifi_initialized);
            system_reboot();
        }

        if (startup_led_active && state.ntp_state.status == NTP_IDLE) {
            cancel_repeating_timer(&startup_led_timer);
            gpio_put(DIAG_RED_LED_GPIO, 0);
            gpio_put(DIAG_GREEN_LED_GPIO, state.flash_config.led_always_on);
            startup_led_active = false;
        }

        sleep_ms(10);
    }

    return 0;
}

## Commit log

2025-08-03 Remove Debug prints
2025-08-10 Switch output to UART
2025-08-28 Tidying includes and new debug print
2025-08-31 Added Pico pinout for reference
2025-08-31 Fixed frame buffer memory overrun
    [lcd.c]
2025-08-31 Switch to v2.2.0 SDK
2025-09-01 Remove unusued I2C library
2025-09-02 Dynamically allocate the frame buffer
2025-09-02 Pass colors to print and clear screen
2025-09-02 Remove camel case
2025-09-03 Lowe case font names
2025-09-03 Lower case font names
2025-09-03 Lower case field names
2025-09-04 Cleaner font names and upper case letters
2025-09-04 Initial timer callback implementation
2025-09-04 Add powman for timers
2025-09-04 Move all Pico SDK calls to a HAL to enable testing
2025-09-07 Change return types to int for failures
    [picow_day_clock.c]
2025-09-07 Clock debug no longer logged in tests
    [lcd.c]
2025-09-07 Change print text to print line at fixed y
    [lcd.h]
2025-09-07 Indent case
2025-09-08 Disable lldb trace
2025-09-08 Implement NTP drift and fix DST calculations
    [picow_day_clock.c]
2025-09-10 Separate test mode and clock debug prints
2025-09-11 lcd_print_line doesn't need to be varargs
    [lcd.c, lcd.h]
2025-09-13 Use gcc-arm-embedded gtom Homebrew
2025-09-13 Revert Pico extension incompatible edits
2025-09-14 Reference pico-sdk in subdirectory
2025-09-15 Switch all native tests to Clang
2025-09-16 Added schematic diagram
2025-09-16 Fix URL to schematic
2025-09-16 Fix schematic paths
2025-09-16 Fix CS wiring
2025-09-16 Fix NTP DNS lookup error handling
    [mock.c]
2025-09-16 Test handling of additional NTP errors
    [mock.c]
2025-09-17 Remove debug to main and add Attach to Pico
2025-09-18 Handle watchdog reset and switch to using red/green icons
    [picow_day_clock.c]
2025-09-18 Fix clobbering of gmtime() buffer
    [picow_day_clock.c]
2025-09-19 Switch to more expressive icons
2025-09-19 Handle test mode icon updates in fatal error
    [picow_day_clock.c]
2025-09-19 Clean up untidy icon case/switch
2025-09-19 Improve test log output and switch to icons
2025-09-20 Clock debug timer simplified
2025-09-20 Initial prototype
2025-09-20 Document prototype status
2025-09-21 Initial thoughts on mechanical design of the LCD connector.
2025-09-22 UDP protocol error coverage
    [mock.c]
2025-09-22 Fix broken preprocessor definitions
    [mock.h, picow_day_clock.c]
2025-09-23 Remove dead function prototype
2025-09-25 Remove frame buffer code and write direct to ST7789
2025-09-25 Fix icon position w/o frame buffer
    [lcd.c]
2025-11-18 Switch clock to lower case weekdays
2025-11-18 Switch to lower case weekdays
2025-11-18 Ensure timeouts are shorter than watchdog
    [config.h]
2025-12-10 New watchdog reboot icons
    [lcd.c]
2025-12-10 Change watchdog icon on reboot
    [picow_day_clock.c]
2025-12-12 Enable build type switch
2025-12-13 Correctly handle NTP error icon in normal operation
    [picow_day_clock.c]
2025-12-14 Run back through main as far as detecting a watchdog reset
    [picow_day_clock.c]
2025-12-14 Moved watchdog error icons into a separate state
    [lcd.c, picow_day_clock.c]
2025-12-15 Separate out NTP status and NTP error enums
    [picow_day_clock.c]
2025-12-15 Removed dead status print code
2025-12-15 Print failures in time tests
2025-12-15 Correct debug print types
    [mock.c]
2025-12-15 Updated status to reflect current Windows build
2025-12-17 Updated prototype status
2025-12-17 Notes about generating CAD drawing
2025-12-18 Fix pitch calculations for total size
2025-12-18 Added STL script command-line.
2026-01-01 Add tab to mount LCD on
2026-01-02 Fix STL instructions
2026-01-23 Always update mock icons to facilitate testing of icon reset
    [mock.c, picow_day_clock.c]
2026-06-13 Added GPIO button to force configuration
2026-06-18 Fix header and body parsing for POST
    [config.h]
2026-06-19 Fix multiple wi-fi init bug
    [picow_day_clock.c]
2026-06-22 KiCad ignores
2026-06-22 Fix mac size overflow bug
    [mock.c]
2026-06-24 Added example of LED flash
2026-06-24 Exclude test_main.c from Pico build
2026-06-24 Fixing address sanitizer memory leaks (Linux)
    [clock.c, mock.h]
2026-06-24 Added mock leak checker
    [clock.c, mock.c, mock.h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]
2026-06-26 Better test printf
2026-06-26 Don't slew large NTP drifts
    [clock.c]
2026-06-26 Handle immediate need to update display on large drift
    [clock.c]
2026-06-28 Remove static NTP and Wi-Fi settings from the Pico build of the clock
2026-06-29 Fix factory reset timing on boot
    [clock.c]
2026-06-29 NTP timeout wired from form
2026-06-29 Correct add_repeating_timer_ms return value
    [mock.c]
2026-07-01 Updated schematic for bare LCDs
    [lcd_module.kicad_sch, pico_dow_clock.kicad_sch]
2026-07-01 Switch to a single shared DC
2026-07-01 Rev0 schematic
    [pico_dow_clock.kicad_sch]
2026-07-02 Rev 0.1 of schematic with no ERC errors/warnings
    [lcd_module.kicad_sch, pico_dow_clock.kicad_sch]
2026-07-02 Initial PCB setup
    [pico_dow_clock.kicad_pcb]
2026-07-05 Reboot after clock reconfig
    [pico_main.c]
2026-07-05 Fix use after bad alloc
    [clock.c]
2026-07-07 Fix tcp_arg mock and support newlines at end of body
    [mock.c]
2026-07-08 Revert strong typing of config store handler
    [clock.c, lcd.h]
2026-07-09 Added LED enable
2026-07-09 Added LED
    [pico_dow_clock.kicad_sch]
2026-07-09 Use bidirectional red-green LED
    [pico_dow_clock.kicad_sch]
2026-07-10 LCD symbol update for new LCD
    [lcd_module.kicad_sch, pico_dow_clock.kicad_pcb, pico_dow_clock.kicad_sch]
2026-07-10 Make active low reset/chip-select clearer
    [lcd.c, lcd.h]
2026-07-10 Fix LCD pinout
    [lcd_module.kicad_sch, pico_dow_clock.kicad_pcb, pico_dow_clock.kicad_sch]
2026-07-10 Retain current flash config for key items
2026-07-10 Don't flip the display any more
    [lcd.c]
2026-07-10 Fix first clock tick regression
    [clock.c]
2026-07-12 Add light sensor for ambient light
    [pico_dow_clock.kicad_sch]
2026-07-13 Added ambient light sensor
    [lcd_module 2.kicad_sch, pico_dow_clock 2.kicad_pcb, pico_dow_clock.kicad_sch]
2026-07-13 Temp fix breaking tests
    [clock.c]
2026-07-14 Calibrate backlight sensor
2026-07-14 Remove backups
    [lcd_module 2.kicad_sch, lcd_module.kicad_sch, pico_dow_clock 2.kicad_pcb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]
2026-07-14 Don't check in Kicad history
2026-07-17 Ignore KiCad backups
2026-07-17 New buffer symbols
    [pico_dow_clock.kicad_sch]
2026-07-17 Fix ADC init
2026-07-17 Remove debugging printf
2026-07-18 Fix mocking of timers
    [mock.c]
2026-07-18 ERC error fixes
    [lcd_module.kicad_sch, pico_dow_clock.kicad_sch]
2026-07-19 Assigned resistor footprints
    [pico_dow_clock.kicad_sch]
2026-07-21 NTP and clock state no longer calloc()ed
    [clock.c, lcd.c, lcd.h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]
2026-07-21 clock_start() no longer needs a return value
    [clock.c, pico_main.c]
2026-08-09 Updates to schematic
    [pico_dow_clock.kicad_sch]
2026-08-10 Fix unsynchronized response test
    [mock.c]
